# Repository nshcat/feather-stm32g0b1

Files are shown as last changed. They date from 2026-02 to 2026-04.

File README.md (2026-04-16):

# prop-devboard

A STM32G0B1-based development board meant for prop making, inspired by Adafruits Feather series of boards

## Features 
* Compatible with most (if not all!) Feather Wing addon boards
* Two independant QWIIC ports, connected to `I2C1` and `I2C2`, respectively
* +3V3 power supply that can deliver 500mA of power
* JST PH2.0 port for LiPo battery, and circuitry for powering off battery:
     * Automatic and safe switching between USB and LiPo battery as power source, even with both connected at the same time
     * Safe battery charging using `MCP73831` over the USB-C port
     * Battery level monitoring using `MAX17048G`
* STDC14 programming header, compatible with STLINK-V3MINIE
* Both HSE (8 MHz) and LSE (32.768 KHz) crystals
* ST M24512-DF 512Kbit I2C EEPROM

## Images

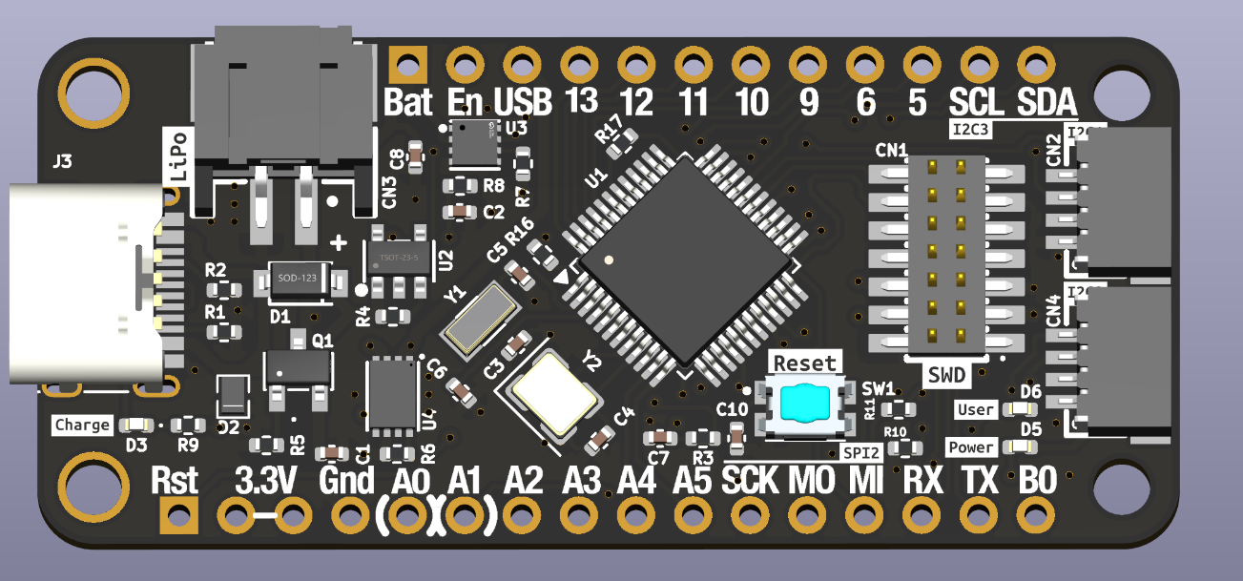
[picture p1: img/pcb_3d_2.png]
Image of the board top the 3d viewer with components Board 3D View \(top, assembled\)


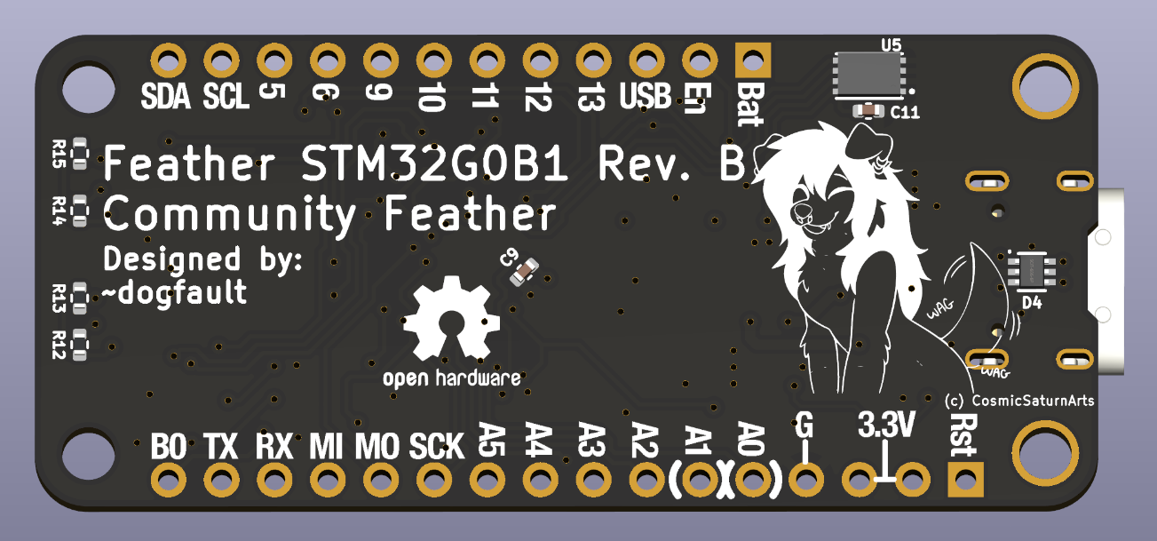
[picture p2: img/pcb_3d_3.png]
Image of the board bottom side in the 3d viewer with components Board 3D View \(bottom\)


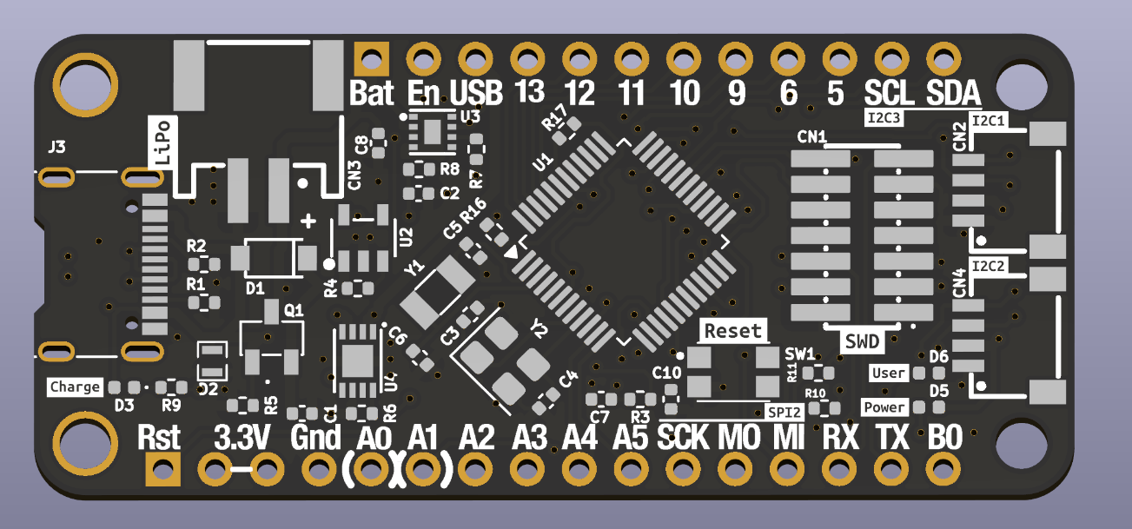
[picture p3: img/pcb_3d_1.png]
Image of the board top side in the 3d viewer without components Board 3D View \(top\)


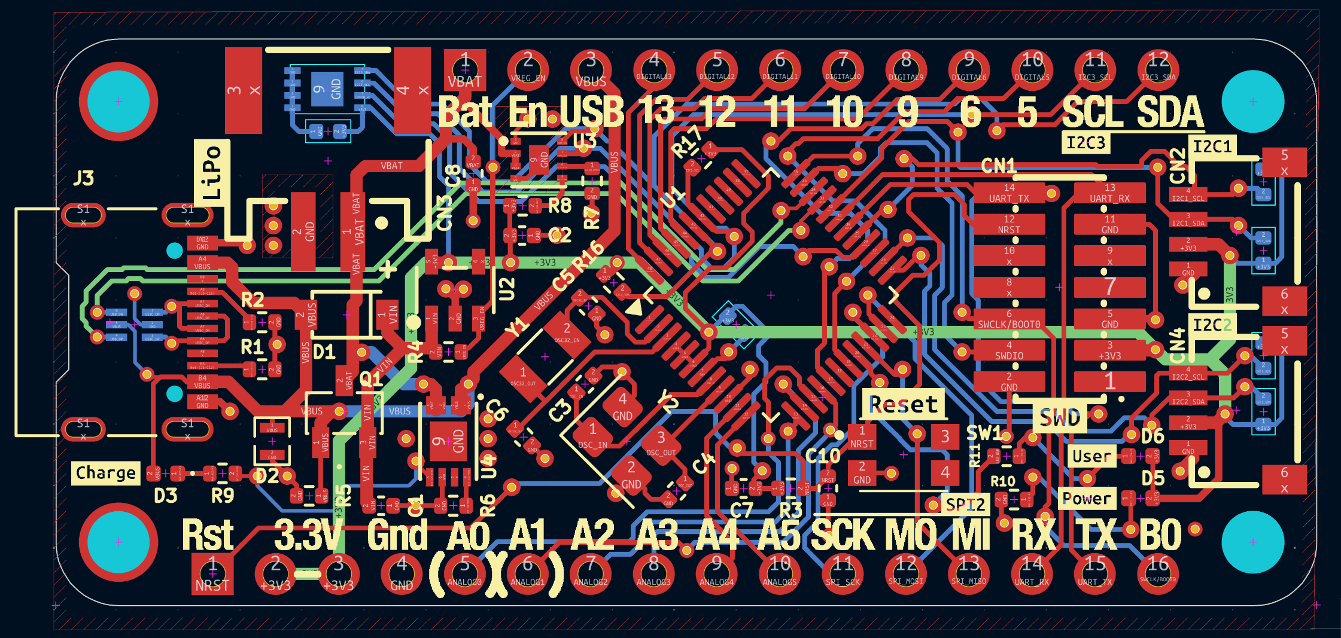
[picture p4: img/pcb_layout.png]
Image of the board layout in PcbNew Board Layout


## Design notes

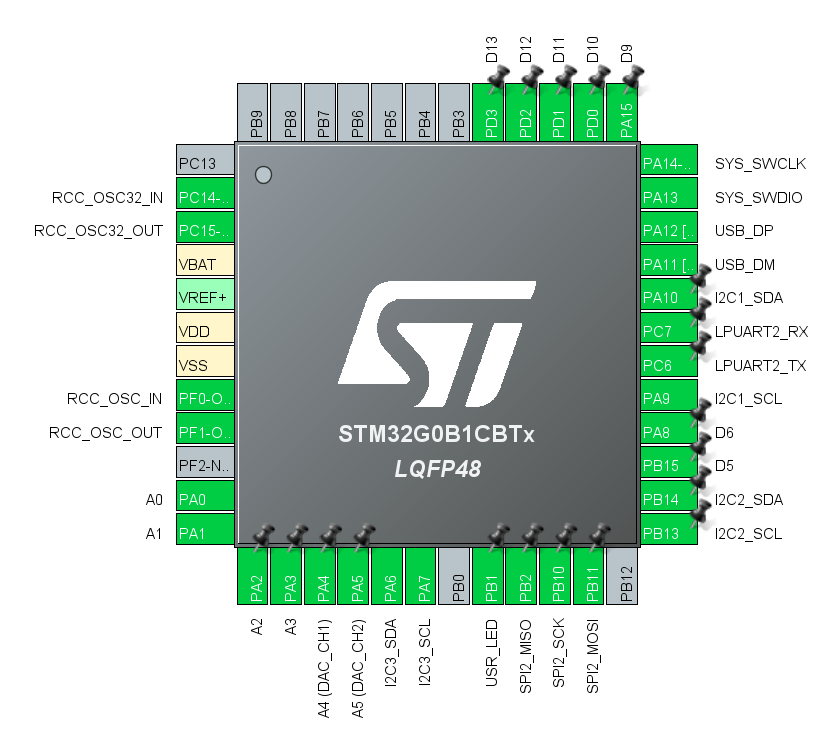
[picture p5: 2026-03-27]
img/pinout_revA.png

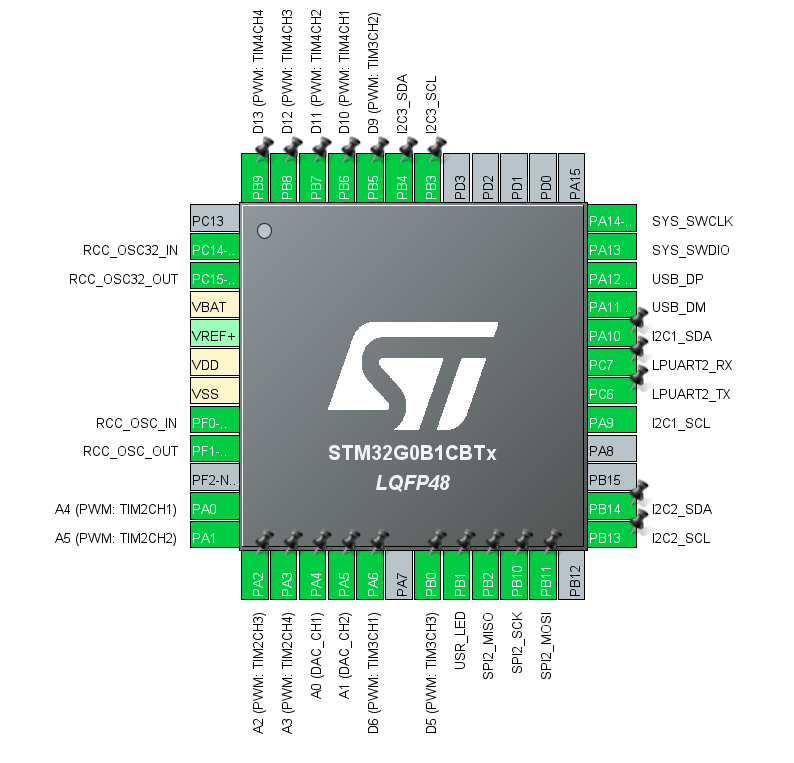
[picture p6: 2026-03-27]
img/pinout_revB.png

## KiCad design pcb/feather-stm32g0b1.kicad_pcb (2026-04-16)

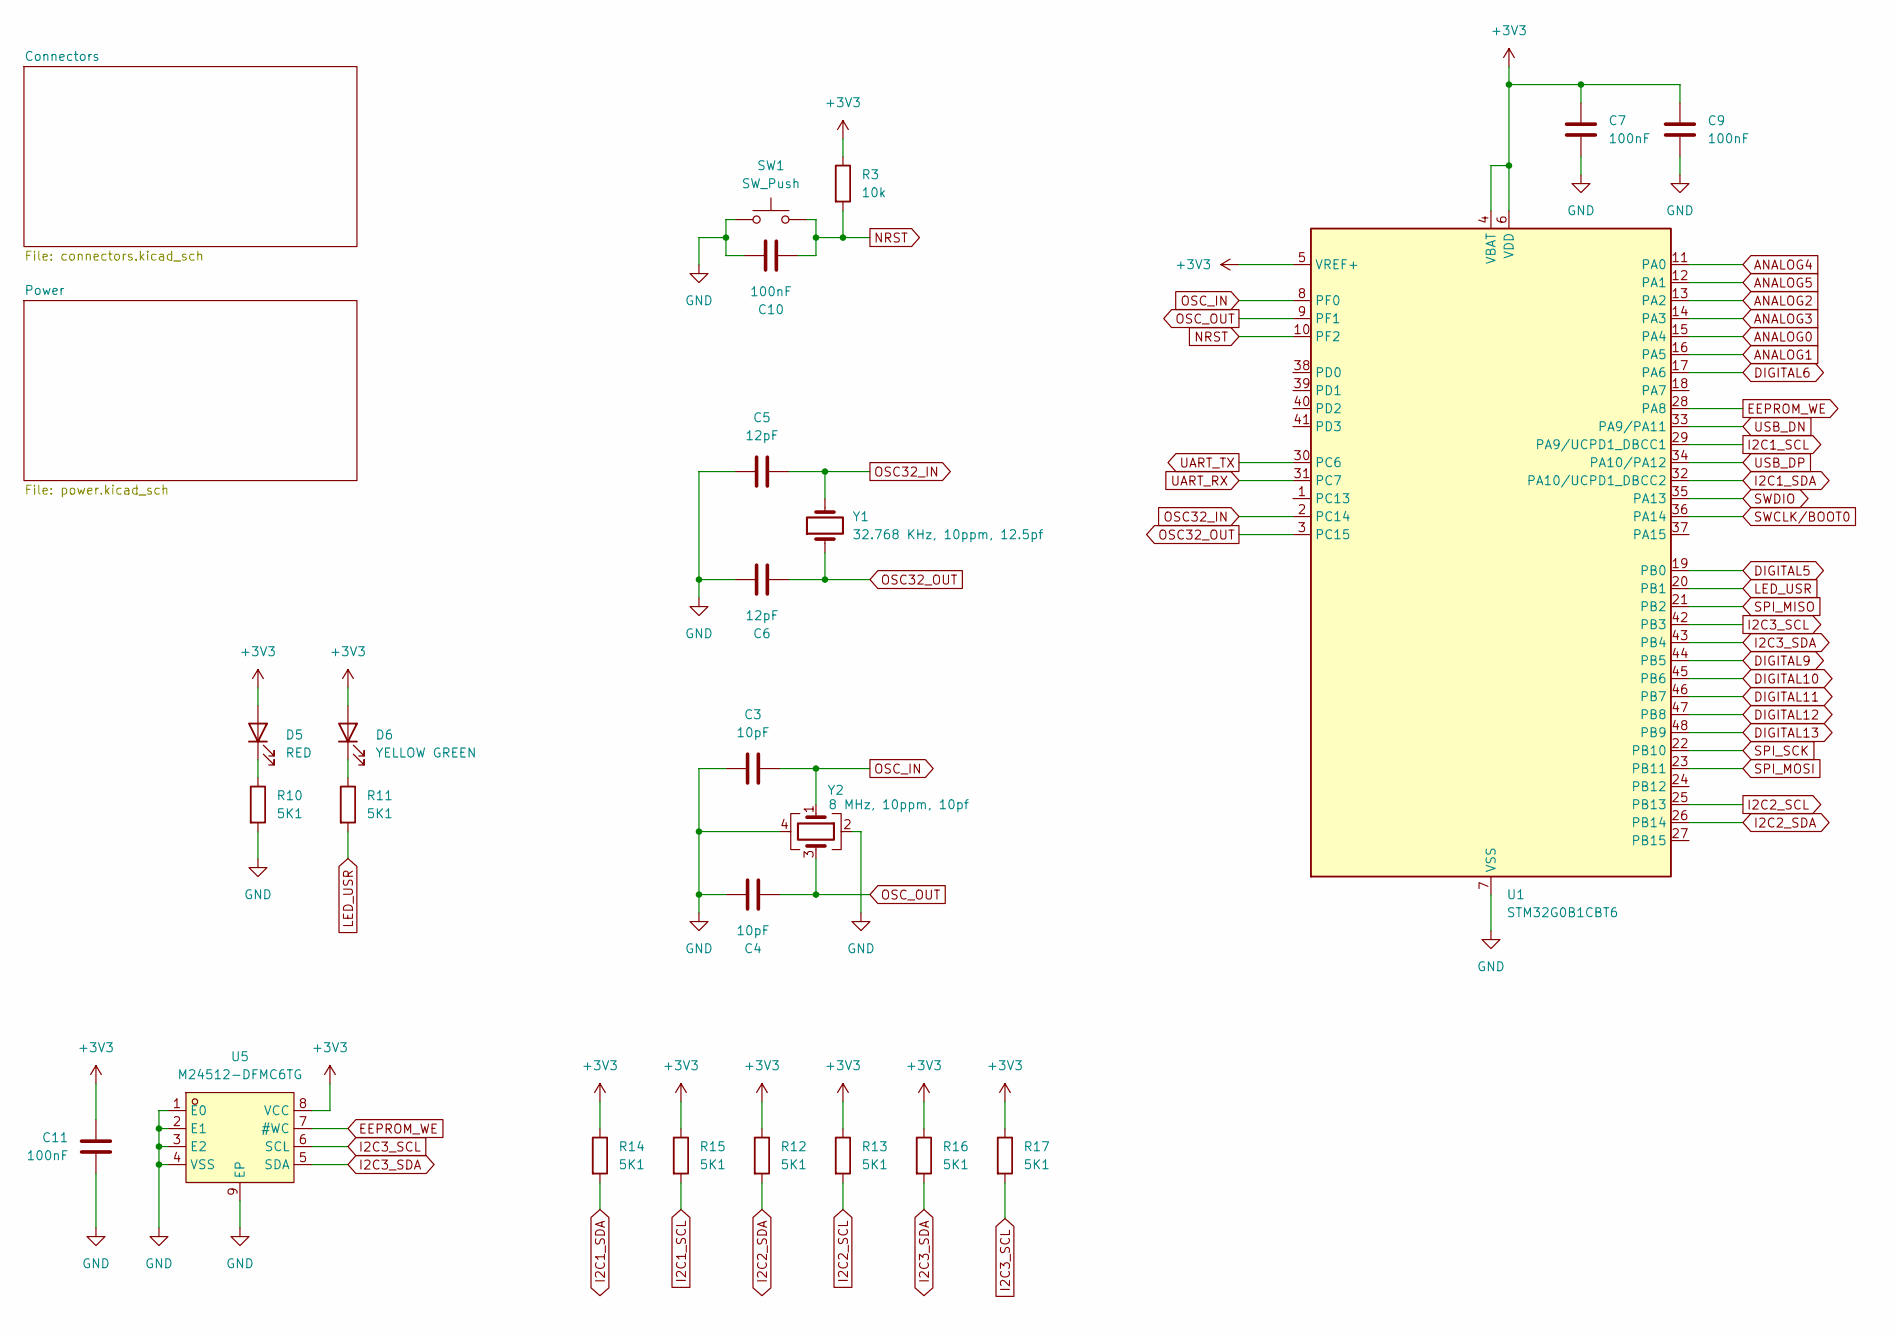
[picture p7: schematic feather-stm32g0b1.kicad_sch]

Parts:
C3, C4: 10pF; C_0402_1005Metric; LCSC Part # C32949
C5, C6: 12pF; C_0402_1005Metric; LCSC Part # C1547
C7, C9, C10, C11: 100nF; C_0402_1005Metric; LCSC Part # C1525
D5: RED; LED_0402_1005Metric; LCSC Part # C130719
D6: YELLOW GREEN; LED_0402_1005Metric; LCSC Part # C130722
R3: 10k; R_0402_1005Metric; LCSC Part # C25744
R10, R11, R12, R13, R14, R15, R16, R17: 5K1; R_0402_1005Metric; LCSC Part # C25905
SW1: SW_Push; WUERTH_434153017835; LCSC Part # C2680612
U1: STM32G0B1CBT6; LQFP-48_7x7mm_P0.5mm; LCSC Part # C2847904
U5: M24512-DFMC6TG; DFN-8_L3.0-W2.0-P0.50-BL-EP; MPN M24512-DFMC6TG; LCSC Part C222237
Y1: 32.768 KHz, 10ppm, 12.5pf; Crystal_SMD_3215-2Pin_3.2x1.5mm; LCSC Part # C32346
Y2: 8 MHz, 10ppm, 10pf; Crystal_SMD_3225-4Pin_3.2x2.5mm; LCSC Part # C400090

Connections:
+3V3: C7.2, C9.2, C11.2, D5.2 (A), D6.2 (A), R3.1, R12.1, R13.1, R14.1, R15.1, R16.1, R17.1, U1.4 (VBAT), U1.5 (VREF+), U1.6 (VDD), U5.8 (VCC); also elsewhere on the board
ANALOG0: U1.15 (PA4); also elsewhere on the board
ANALOG1: U1.16 (PA5); also elsewhere on the board
ANALOG2: U1.13 (PA2); also elsewhere on the board
ANALOG3: U1.14 (PA3); also elsewhere on the board
ANALOG4: U1.11 (PA0); also elsewhere on the board
ANALOG5: U1.12 (PA1); also elsewhere on the board
DIGITAL5: U1.19 (PB0); also elsewhere on the board
DIGITAL6: U1.17 (PA6); also elsewhere on the board
DIGITAL9: U1.44 (PB5); also elsewhere on the board
DIGITAL10: U1.45 (PB6); also elsewhere on the board
DIGITAL11: U1.46 (PB7); also elsewhere on the board
DIGITAL12: U1.47 (PB8); also elsewhere on the board
DIGITAL13: U1.48 (PB9); also elsewhere on the board
EEPROM_WE: U1.28 (PA8), U5.7 (#WC)
GND: C3.2, C4.2, C5.1, C6.2, C7.1, C9.1, C10.1, C11.1, R10.2, SW1.2, U1.7 (VSS), U5.1 (E0), U5.2 (E1), U5.3 (E2), U5.4 (VSS), U5.9 (EP), Y2.2, Y2.4; also elsewhere on the board
I2C1_SCL: R15.2, U1.29 (PA9/UCPD1_DBCC1); also elsewhere on the board
I2C1_SDA: R14.2, U1.32 (PA10/UCPD1_DBCC2); also elsewhere on the board
I2C2_SCL: R13.2, U1.25 (PB13); also elsewhere on the board
I2C2_SDA: R12.2, U1.26 (PB14); also elsewhere on the board
I2C3_SCL: R17.2, U1.42 (PB3), U5.6 (SCL); also elsewhere on the board
I2C3_SDA: R16.2, U1.43 (PB4), U5.5 (SDA); also elsewhere on the board
LED_USR: R11.2, U1.20 (PB1)
NRST: C10.2, R3.2, SW1.1, U1.10 (PF2); also elsewhere on the board
unnamed: D5.1 (K), R10.1
unnamed: D6.1 (K), R11.1
OSC32_IN: C5.2, U1.2 (PC14), Y1.2
OSC32_OUT: C6.1, U1.3 (PC15), Y1.1
OSC_IN: C3.1, U1.8 (PF0), Y2.1
OSC_OUT: C4.1, U1.9 (PF1), Y2.3
SPI_MISO: U1.21 (PB2); also elsewhere on the board
SPI_MOSI: U1.23 (PB11); also elsewhere on the board
SPI_SCK: U1.22 (PB10); also elsewhere on the board
SWCLK/BOOT0: U1.36 (PA14); also elsewhere on the board
SWDIO: U1.35 (PA13); also elsewhere on the board
UART_RX: U1.31 (PC7); also elsewhere on the board
UART_TX: U1.30 (PC6); also elsewhere on the board
USB_DN: U1.33 (PA9/PA11); also elsewhere on the board
USB_DP: U1.34 (PA10/PA12); also elsewhere on the board

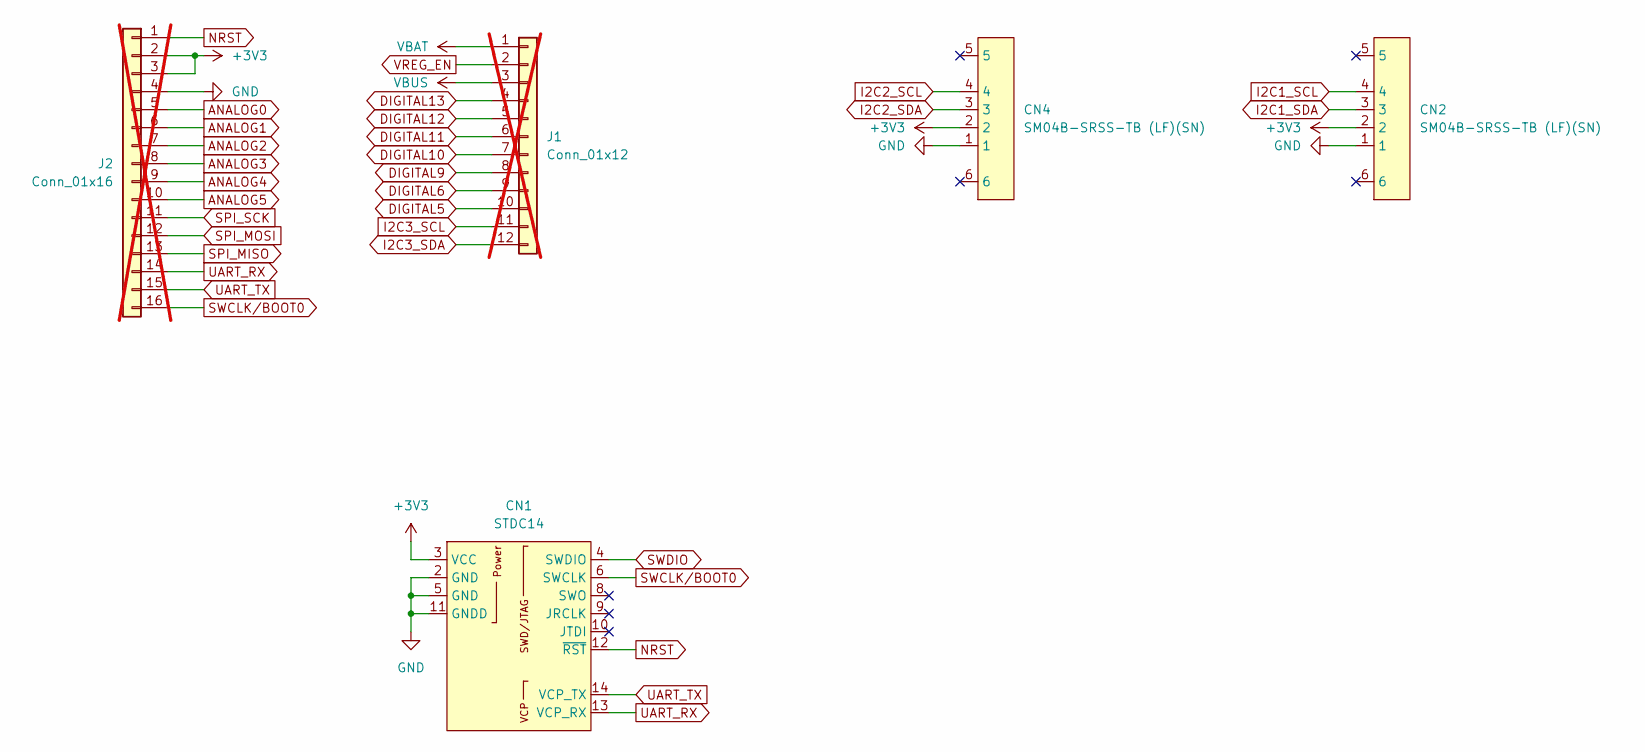
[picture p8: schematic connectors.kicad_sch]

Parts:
CN1: STDC14; HDR-SMD_14P-P1.27-V-M-R2-C7-LS5.8_FTS-107-03-X-DV; LCSC Part # C46971079
CN2, CN4: SM04B-SRSS-TB (LF)(SN); CONN-SMD_4P-P1.00_SM04B-SRSS-TB-LF-SN; LCSC Part C19270571
J1: Conn_01x12; PinHeader_1x12_P2.54mm_Vertical; not fitted
J2: Conn_01x16; PinHeader_1x16_P2.54mm_Vertical; not fitted

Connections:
+3V3: CN1.3 (VCC), CN2.2, CN4.2, J2.2, J2.3; also elsewhere on the board
ANALOG0: J2.5; also elsewhere on the board
ANALOG1: J2.6; also elsewhere on the board
ANALOG2: J2.7; also elsewhere on the board
ANALOG3: J2.8; also elsewhere on the board
ANALOG4: J2.9; also elsewhere on the board
ANALOG5: J2.10; also elsewhere on the board
DIGITAL5: J1.10; also elsewhere on the board
DIGITAL6: J1.9; also elsewhere on the board
DIGITAL9: J1.8; also elsewhere on the board
DIGITAL10: J1.7; also elsewhere on the board
DIGITAL11: J1.6; also elsewhere on the board
DIGITAL12: J1.5; also elsewhere on the board
DIGITAL13: J1.4; also elsewhere on the board
GND: CN1.2 (GND), CN1.5 (GND), CN1.11 (GNDD), CN2.1, CN4.1, J2.4; also elsewhere on the board
I2C1_SCL: CN2.4; also elsewhere on the board
I2C1_SDA: CN2.3; also elsewhere on the board
I2C2_SCL: CN4.4; also elsewhere on the board
I2C2_SDA: CN4.3; also elsewhere on the board
I2C3_SCL: J1.11; also elsewhere on the board
I2C3_SDA: J1.12; also elsewhere on the board
NRST: CN1.12 (~RST), J2.1; also elsewhere on the board
SPI_MISO: J2.13; also elsewhere on the board
SPI_MOSI: J2.12; also elsewhere on the board
SPI_SCK: J2.11; also elsewhere on the board
SWCLK/BOOT0: CN1.6 (SWCLK), J2.16; also elsewhere on the board
SWDIO: CN1.4 (SWDIO); also elsewhere on the board
UART_RX: CN1.13 (VCP_RX), J2.14; also elsewhere on the board
UART_TX: CN1.14 (VCP_TX), J2.15; also elsewhere on the board
VBAT: J1.1; also elsewhere on the board
VBUS: J1.3; also elsewhere on the board
VREG_EN: J1.2; also elsewhere on the board

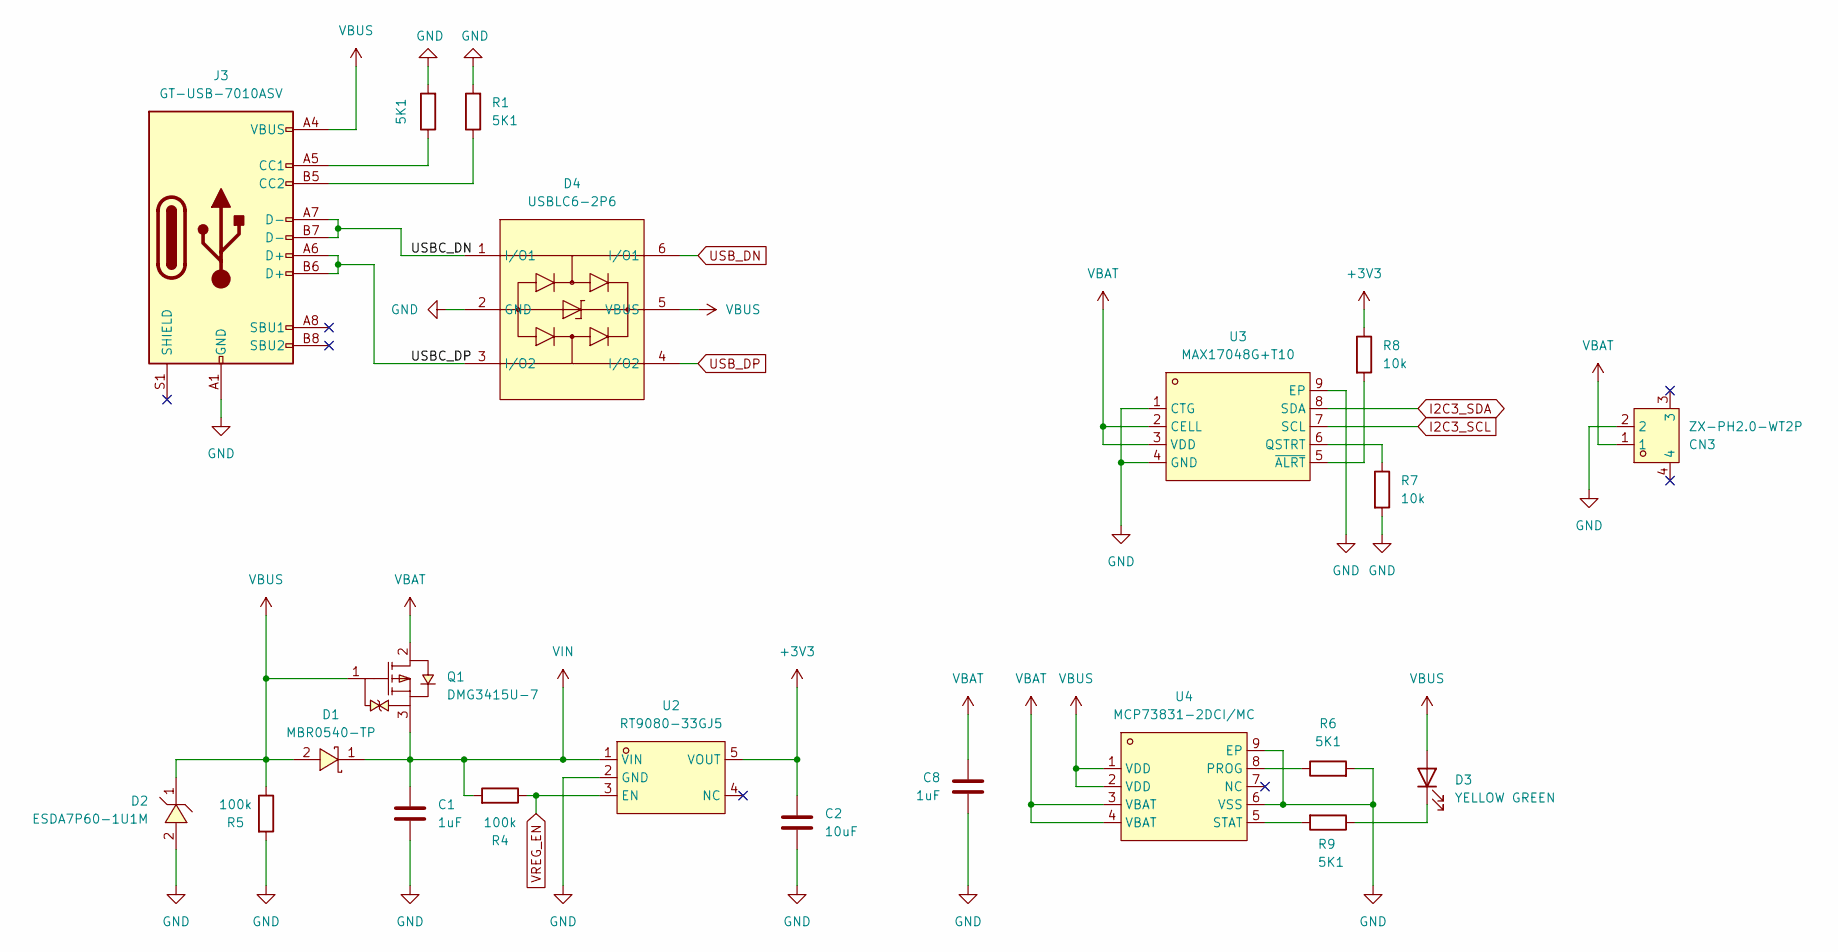
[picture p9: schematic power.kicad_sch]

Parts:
C1, C8: 1uF; C_0402_1005Metric; LCSC Part # C14445
C2: 10uF; C_0402_1005Metric; LCSC Part # C15525
CN3: ZX-PH2.0-WT2P; CONN-SMD_PH-2AWT; LCSC Part C19633668
D1: MBR0540-TP; SOD-123_L2.7-W1.6-LS3.7-RD; LCSC Part C78744
D2: ESDA7P60-1U1M; D1610-RD; LCSC Part C1975146
D3: YELLOW GREEN; LED_0402_1005Metric; LCSC Part # C130722
D4: USBLC6-2P6; SOT-666-6_L1.6-W1.2-P0.50-LS1.6-BR; LCSC Part C15999
J3: GT-USB-7010ASV; USB_C_Receptacle_G-Switch_GT-USB-7010ASV; LCSC Part # C2988369
Q1: DMG3415U-7; SOT-23-3_L2.9-W1.6-P1.90-LS2.8-BR-CW; LCSC Part C96616
R1, R2, R6, R9: 5K1; R_0402_1005Metric; LCSC Part # C25905
R4: 100k; R_0402_1005Metric; LCSC Part # C60491
R5: 100k; R_0402_1005Metric; LCSC Part # C25741
R7, R8: 10k; R_0402_1005Metric; LCSC Part # C25744
U2: RT9080-33GJ5; TSOT-23-5_L2.9-W1.6-P0.95-LS2.8-BL; LCSC Part C841192
U3: MAX17048G+T10; TDFN-8_L2.0-W2.0-P0.50-BL-EP1.2; LCSC Part C2682616
U4: MCP73831-2DCI/MC; DFN-8_L3.0-W2.0-P0.50-BL-EP1.6; LCSC Part C635037

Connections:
+3V3: C2.2, R8.1, U2.5 (VOUT); also elsewhere on the board
/Power/USBC_DN: D4.1 (I/O1), J3.A7 (D-), J3.B7 (D-)
/Power/USBC_DP: D4.3 (I/O2), J3.A6 (D+), J3.B6 (D+)
GND: C1.1, C2.1, C8.1, CN3.2, D2.2, D4.2 (GND), J3.A1 (GND), J3.A12 (GND), J3.B1 (GND), J3.B12 (GND), R1.2, R2.2, R5.2, R6.2, R7.2, U2.2 (GND), U3.1 (CTG), U3.4 (GND), U3.9 (EP), U4.6 (VSS), U4.9 (EP); also elsewhere on the board
I2C3_SCL: U3.7 (SCL); also elsewhere on the board
I2C3_SDA: U3.8 (SDA); also elsewhere on the board
unnamed: D3.1 (K), R9.1
unnamed: J3.A5 (CC1), R2.1
unnamed: J3.B5 (CC2), R1.1
unnamed: R7.1, U3.6 (QSTRT)
unnamed: R8.2, U3.5 (~ALRT)
unnamed: R6.1, U4.8 (PROG)
unnamed: R9.2, U4.5 (STAT)
USB_DN: D4.6 (I/O1); also elsewhere on the board
USB_DP: D4.4 (I/O2); also elsewhere on the board
VBAT: C8.2, CN3.1, Q1.2, U3.2 (CELL), U3.3 (VDD), U4.3 (VBAT), U4.4 (VBAT); also elsewhere on the board
VBUS: D1.2, D2.1, D3.2 (A), D4.5 (VBUS), J3.A4 (VBUS), J3.A9 (VBUS), J3.B4 (VBUS), J3.B9 (VBUS), Q1.1, R5.1, U4.1 (VDD), U4.2 (VDD); also elsewhere on the board
VIN: C1.2, D1.1, Q1.3, R4.2, U2.1 (VIN)
VREG_EN: R4.1, U2.3 (EN); also elsewhere on the board

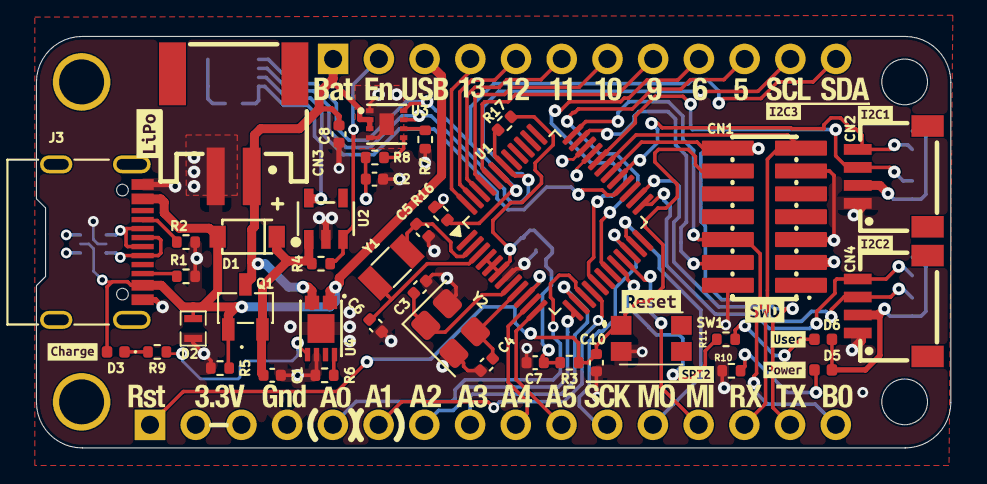
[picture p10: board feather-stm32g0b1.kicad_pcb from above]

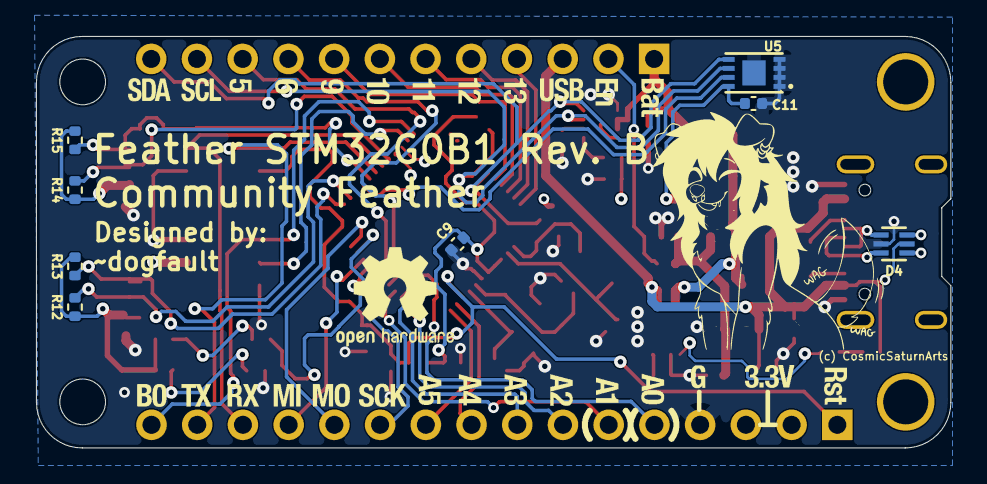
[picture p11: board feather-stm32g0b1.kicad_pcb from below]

Board: 4 copper layers, 50.8 x 22.9 mm, 62 parts (9 on the bottom side), 52 nets.

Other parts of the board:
U$24: PINLABELS_TOP
U$40: Val**; PINLABELS_BOT
kibuzzard-69DFDE44: G***; kibuzzard-69DFDE44
kibuzzard-69DFDEC0: G***; kibuzzard-69DFDEC0
kibuzzard-69DFDEEF: G***; kibuzzard-69DFDEEF
kibuzzard-69DFDF04: G***; kibuzzard-69DFDF04
kibuzzard-69DFDF67: G***; kibuzzard-69DFDF67
kibuzzard-69DFDFA3: G***; kibuzzard-69DFDFA3
kibuzzard-69DFDFE1: G***; kibuzzard-69DFDFE1
kibuzzard-69DFDFEF: G***; kibuzzard-69DFDFEF
kibuzzard-69DFE1A1: G***; kibuzzard-69DFE1A1
kibuzzard-69DFE014: G***; kibuzzard-69DFE014

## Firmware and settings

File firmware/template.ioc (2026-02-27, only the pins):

Mcu.UserName=STM32G0B1CBTx
PA0.Signal=ADC1_IN0
PA1.Signal=ADC1_IN1
PA10.Signal=I2C1_SDA
PA13.Signal=SYS_SWDIO
PA14-BOOT0.Signal=SYS_SWCLK
PA2.Signal=ADC1_IN2
PA3.Signal=ADC1_IN3
PA4.Signal=ADC1_IN4
PA5.Signal=ADC1_IN5
PA9.Signal=I2C1_SCL
PB10.Signal=SPI2_SCK
PB11.Signal=SPI2_MOSI
PB13.Signal=I2C2_SCL
PB14.Signal=I2C2_SDA
PB2.Signal=SPI2_MISO
PB3.Signal=I2C3_SCL
PB4.Signal=I2C3_SDA
PC6.Signal=LPUART2_TX
PC7.Signal=LPUART2_RX

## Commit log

2026-02-20 Initial work on PCB
    [connectors.kicad_sch, power.kicad_sch, prop-devboard.kicad_pcb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]
2026-02-23 Work on schematics
    [connectors.kicad_sch]
2026-02-25 Added CubeMX template, and more schematics work
    [connectors.kicad_sch, prop-devboard.kicad_pcb, prop-devboard.kicad_sch]
2026-02-25 Lots of work on schematics
    [connectors.kicad_sch, power.kicad_sch, prop-devboard.kicad_pcb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]
2026-02-27 Added TLV755 LDO symbol and footprint
2026-02-27 Mostly finished PCB layout
    [connectors.kicad_sch, power.kicad_sch, prop-devboard.kicad_pcb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]
2026-02-27 Added USB support
    [power.kicad_sch, prop-devboard.kicad_pcb, prop-devboard.kicad_sch]
2026-02-27 Improved track connection to USB VBUS pads (was too thin)
    [prop-devboard.kicad_pcb]
2026-02-28 Added power and status LEDs to the design
    [prop-devboard.kicad_pcb, prop-devboard.kicad_sch]
2026-02-28 Added revision number
    [prop-devboard.kicad_pcb]
2026-03-01 Fixed various issues encountered during DFM checks
    [prop-devboard.kicad_pcb]
2026-03-04 Added silkscreen art to pcb
    [prop-devboard.kicad_pcb]
2026-03-04 Fixed MCU power pins not being connected correctly
    [connectors.kicad_sch, prop-devboard.kicad_pcb, prop-devboard.kicad_sch]
2026-03-07 Fixed wrong polarity of the battery connector, uffff
    [power.kicad_sch, prop-devboard.kicad_pcb]
2026-03-14 Updated silkscreen to show battery polarity, as well as I2C and SPI peripheral numbers
    [prop-devboard.kicad_pcb]
2026-03-21 Renamed kicad project
    [feather-stm32g0b1.kicad_pcb, feather-stm32g0b1.kicad_sch]
2026-03-27 Lots more work on RevB schematics and pcb
    [feather-stm32g0b1.kicad_pcb, feather-stm32g0b1.kicad_sch]
2026-03-31 Added black clone JST PH 2 pin male header
2026-04-02 Added black JST SH clone pin header
2026-04-02 Fixed clone JST PH header footprint orientation
2026-04-02 Smaller fixes to JST PH header footprint
2026-04-02 Switched battery and QWIIC connectors to black ones, and fixed their positioning to not obstruct bolt heads when M2.5 cylindrical bolts are used to mount the board
    [connectors.kicad_sch, feather-stm32g0b1.kicad_pcb, power.kicad_sch]
2026-04-02 Added I2C pull ups, extra bypass capacitance for the MCU and increased the LDO output capacitance
    [feather-stm32g0b1.kicad_pcb, feather-stm32g0b1.kicad_sch, power.kicad_sch]
2026-04-02 More PCB layout updates
    [feather-stm32g0b1.kicad_pcb, feather-stm32g0b1.kicad_sch, power.kicad_sch]
2026-04-02 Some minor pcb changes
    [feather-stm32g0b1.kicad_pcb]
2026-04-15 Upgraded kicad project to kicad 10
    [connectors.kicad_sch, feather-stm32g0b1.kicad_pcb, feather-stm32g0b1.kicad_sch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]
2026-04-15 Updated some diode symbols that were skewed
    [power.kicad_sch]
2026-04-15 Used kibuzzard to generate nice labels for buttons, ports and leds
    [feather-stm32g0b1.kicad_pcb, feather-stm32g0b1.kicad_sch]
2026-04-16 Added I2C EEPROM to the board
    [feather-stm32g0b1.kicad_pcb, feather-stm32g0b1.kicad_sch]
